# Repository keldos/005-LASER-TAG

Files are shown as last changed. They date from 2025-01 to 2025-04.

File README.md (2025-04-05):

# Wireless Comms, OLED Screen, and Ultra Beam Game for Laser Tag

## Description

This hack for the [Crunchlabs Hack Pack Box 5 - Laser Tag](https://www.crunchlabs.com/products/laser) adds an OLED screen that displays information for custom game modes, plus wireless communication between blasters using the nRF24L01+. The wireless comms enable new game mechanics such as an EMP blast and hit confirmation.

<p float="left">
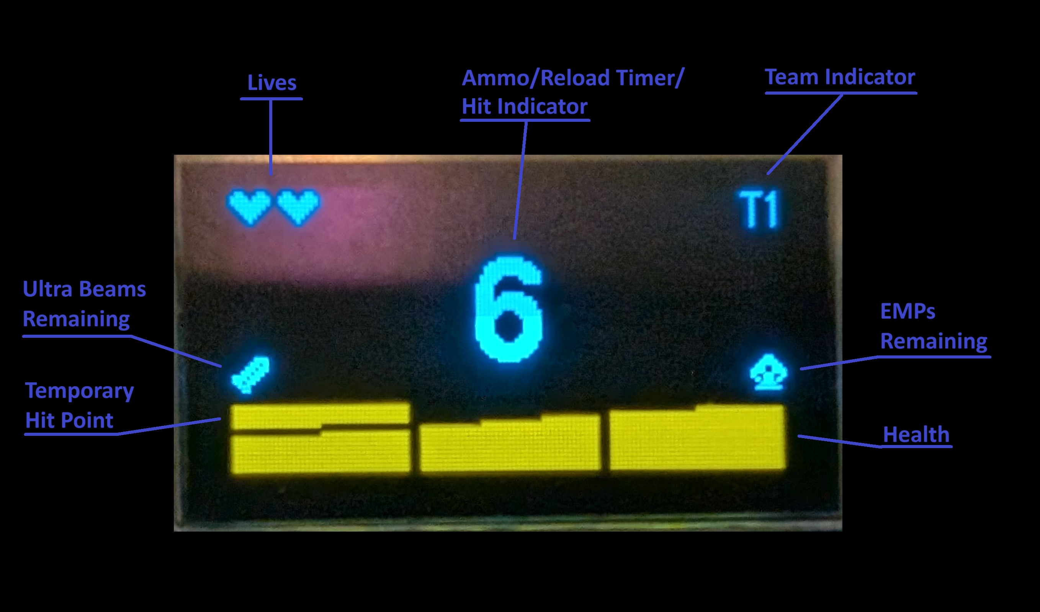
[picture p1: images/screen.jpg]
Screen with labels
  
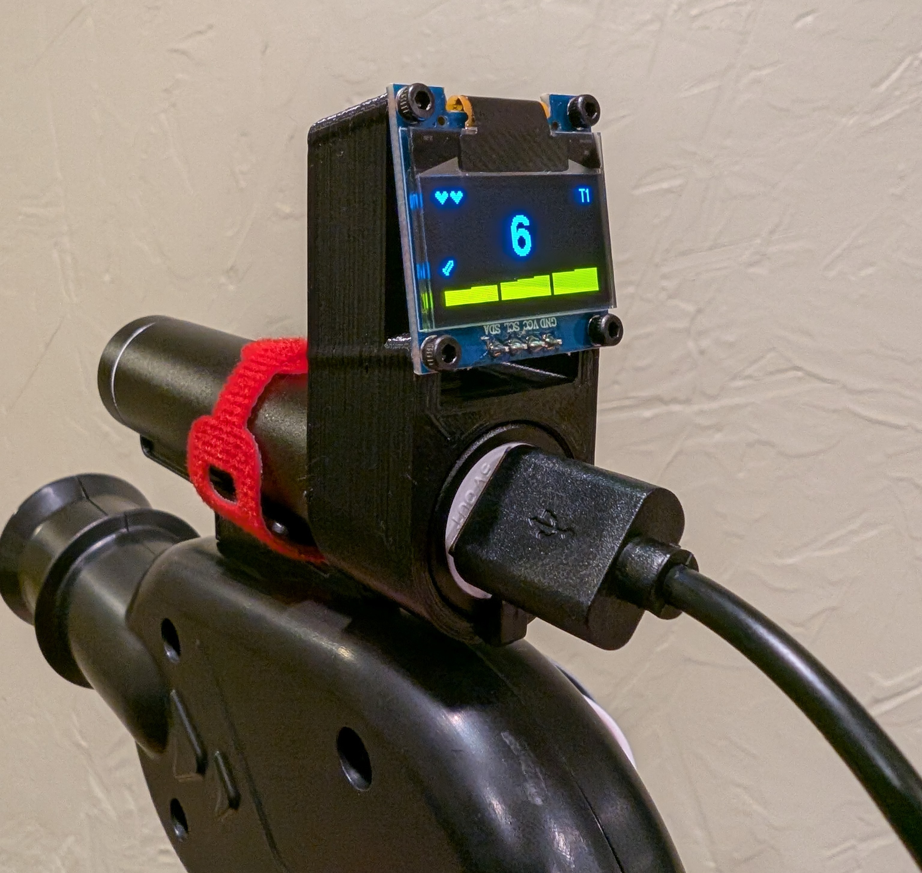
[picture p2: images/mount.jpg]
Screen mounted on battery
  
</p>

## Game Mechanics

* **Lives** - Each player starts with **2 lives**
* **Game Over** - Players reduced to 0 lives are out of the game with a **Game Over** screen
* **3 Health per life** – The goggles dim by 1/3 per health lost
* **6 Max Ammo** – Reload 1 ammo per second while holding the reload button
* **Ultra Beam:**
  * Charge the **Ultra Beam** by holding reload for 5 seconds when your ammo is maxed out
  * Fire a devastating shot that reduces your target's health to 0, but at a cost:
    * Lose 1 health
    * Consume all your ammo
    * Only 1 Ultra Beam per game
  * Make it count!
* **Team Selection** - When the game starts, you must select a team
  * Press reload to change teams
  * Hold the trigger for 2 seconds to start the game for everyone
  * Player icons are displayed indicating the number of players on each team
* **Successful Hit Indicator** - If a shot hits an enemy, the hit indicator will briefly display on your screen
  * The indicator changes slightly when your hit is a regular shot, Ultra Beam, or an elimination
* **Victory Screen** - If all opposing teams are eliminated, a victory screen will display
* **EMP Blast:**
  * An **EMP blast** is awarded when you are hit by an opponent's **Ultra Beam**
  * Hold the reload button and the trigger for 1 second to detonate an EMP blast
    * Grants you and nearby teammates with 1 temporary hitpoint for 20 seconds
      * The temporary hitpoint also protects you from Ultra Beam overload damage
    * Disables nearby enemies for 4 seconds
      * Disabled enemies can still be hit!
  * Coordinate for a devastating counter attack!

## OLED Screen Features

Displays critical game info, including:
* Ammo count
* Team number
* Lives
* Which team hit you
* Whether you were hit by an **Ultra Beam**

## Hardware

* [Crunchlabs Hack Pack Box 5 - Laser Tag](https://www.crunchlabs.com/products/laser)
* 2 [0.96 Inch OLED I2C Display Module](https://amzn.com/dp/B09C5K91H7)
* 2 [nRF24L01+ 2.4GHz Wireless RF Transceivers](https://amzn.com/dp/B07GZ17ZWS)
* 2 [Push Buttons](https://amzn.com/dp/B07ZV3PB26) for reload - Something with more of a click would be better
* 2 [3v Mini Vibration Motors](https://amzn.com/dp/B0B4SK8M1C)
* [Dupont Wires](https://amzn.com/dp/B07GD2BWPY)
* A 3D printer or access to one to print the screen mount (alternatively, the screen can be held on by strapping the wires down with the velcro battery strap)
* A Hot glue gun - The vibration motor adhesive did not hold
* A soldering iron
* 8 M2 screws - 4mm or longer
* Needle nose pliers - to remove plastic to make room for the nRF24L01+

## Wiring

### OLED:
* SDA -> A4
* SCL -> A5
* VCC -> 5v Rail
* GND -> GND Rail

### nRF24L01+:
* VCC -> 3v3 (NOT 5v!)
* GND -> GND Rail
* CE -> D2
* CSN -> D4
* MOSI -> D11
* MISO -> D12
* SCK -> D13

### Reload Button:
* Positive Terminal -> A0
* Negative Terminal -> GND Rail

### Vibration Motor:
* Positive Wire -> A2
* Negative Wire -> GND Rail

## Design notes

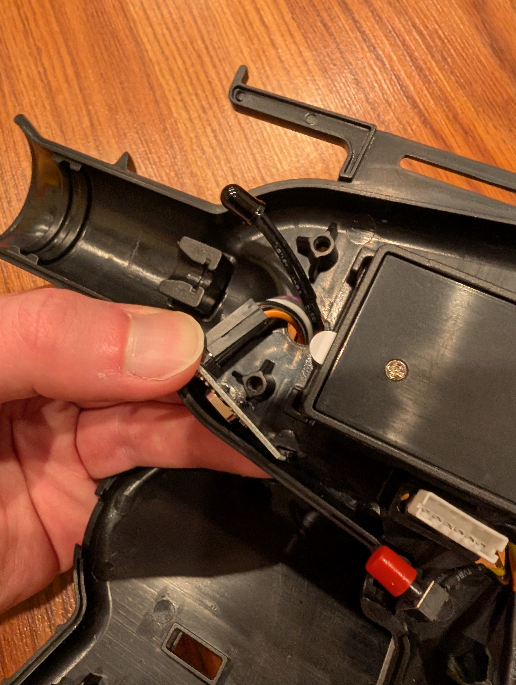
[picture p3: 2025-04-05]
images/rf-module.jpg

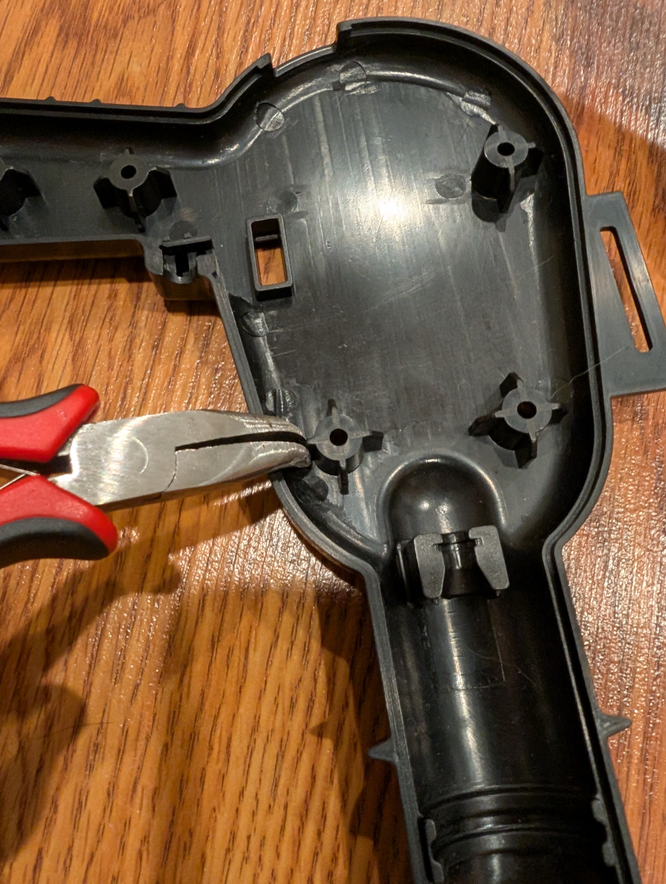
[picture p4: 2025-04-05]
images/remove-plastic.jpg

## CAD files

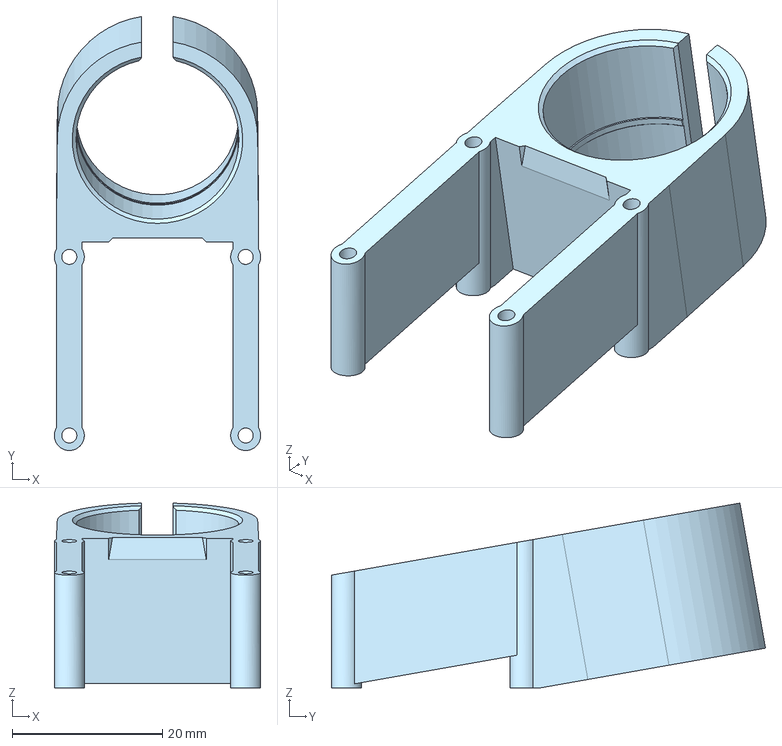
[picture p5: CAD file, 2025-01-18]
models/screen-mount.step
27.5 x 57.8 x 24.6 mm

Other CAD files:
models/screen-mount.3mf
models/screen-mount.stl

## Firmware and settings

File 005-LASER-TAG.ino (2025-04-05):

/*
  ************************************************************************************
  * MIT License
  *
  * Copyright (c) 2023 Crunchlabs LLC (Laser Tag Code)

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
  ************************************************************************************
*/

// >>>>>>>>>>>>>>>>>>>>>>>>>>>> PIN DEFINITIONS <<<<<<<<<<<<<<<<<<<<<<<<<<<<
#define IR_SEND_PIN         3
#define IR_RECEIVE_PIN      5
#define _IR_TIMING_TEST_PIN 7

#define SERVO_PIN       9

#define RELOAD_PIN      14 // A0 pin
#define BUZZER_PIN      16 // A2 pin
#define TRIGGER_PIN     17 // A3 pin

#define COMMS_CE        2
#define COMMS_CSN       4

// >>>>>>>>>>>>>>>>>>>>>>>>>>>>>>> LIBRARIES <<<<<<<<<<<<<<<<<<<<<<<<<<<<<<<
#define DECODE_NEC              // defines RIR Protocol (Apple and Onkyo)

#include <IRremote.hpp>
#include <Arduino.h>
#include <Servo.h>
#include <U8g2lib.h>

#include <SPI.h>
#include <nRF24L01.h>
#include <RF24.h>

RF24 radio(COMMS_CE, COMMS_CSN); // CE, CSN
const byte address[6] = "00001";

enum class PacketType {
  Undefined,
  IAm,
  IAmError,
  StartGame,
  EMP,
  ImHit,
  ImEliminated,
};

struct DataPacket {
  unsigned int uniqueID = 0;
  PacketType type = PacketType::Undefined;
  uint8_t playerId = 255;
};

#define MAX_TEAM_PLAYERS    8 // Must be even!
#define ID_OFFSET           MAX_TEAM_PLAYERS
#define ID_RANGE            MAX_TEAM_PLAYERS * 2
unsigned long lastHeartbeat = 0;
unsigned int randomDelay = 1245;

char errorMsg[50];
bool displayError = false;

Servo myservo;
U8G2_SSD1306_128X64_NONAME_1_HW_I2C u8g2(U8G2_R2, U8X8_PIN_NONE);

uint8_t numHalfWidth[10] = {9,7,9,9,8,9,9,9,9,9};

// >>>>>>>>>>>>>>>>>>>>>>>>>>> GAME PARAMETERS <<<<<<<<<<<<<<<<<<<<<<<<<<<<<
#define DEBOUNCE_DELAY 20

#define SERVO_INITIAL_POS 150     // how agressively to undarken goggles
#define SERVO_READY_POS 120       // reduce aggresiveness near end of action
#define SERVO_STOP 90             // Stop the servo
#define SERVO_HIT_POS 50          // Darken all the way
#define SERVO_TIME_TO_33 400      // ms needed to darken by 1/3
#define SERVO_TIME_TO_66 800      // ms needed to darken by 2/3
#define SERVO_TIME_TO_100 1200    // ms needed to darken all the way

#define TRIGGER_COOLDOWN 500      // milliseconds
#define HIT_TIMEOUT 8000          // milliseconds
#define START_GAME_HOLD 2000      // milliseconds
#define EMP_HOLD 1000             // milliseconds
#define START_GAME_COUNTDOWN 4000 // milliseconds
#define DISABLED_TIMEOUT 4000     // milliseconds
#define SHIELD_TIMER 20000        // milliseconds
#define RELOAD_TIME_EACH 1000     // milliseconds
#define CHARGE_ULTRA_BEAM 5000    // milliseconds
#define HIT_INDICATOR 2000        // milliseconds

const uint8_t maxAmmo = 6;
const uint8_t maxEMP = 1;
const bool deathTakesAmmo = true;
uint8_t playerId = 255;
uint8_t playerIdx = 255;
unsigned int uniqueID;
bool eliminated = false;
uint8_t eliminatedMe = 0;

uint8_t lastTriggerVal = 1;                 // trigger debounce variable
unsigned long lastTDebounceTime = 0;        // trigger button debounce time
uint8_t triggerState;                       // trigger debounce result
bool buttonWasReleased = true;              // release check, no "full auto"
unsigned long previousTriggerMillis = 0;    // cooldown timestamp between shots
unsigned long hitIndicatorTime = 0;         // hit indicator timeout

uint8_t lastReloadVal = 1;                  // reload button, debounce
unsigned long lastRDebounceTime = 0;        // reload button debounce time
uint8_t reloadState;                        // reload button debounce result
unsigned long buzzerTime = 0;               // when the buzzer should stop

unsigned long reloadTimer = -CHARGE_ULTRA_BEAM - 1000; // time to add shots to ammo bar

enum class GamePhase {
  PressStart,
  TeamSelect,
  GameCountdown,
  GameInProgress,
  GameOver,
};

enum class HitIndicator {
  None,
  Hit,
  UltraBeamHit,
  Elimination,
};

struct GameData {
  uint8_t ammo = maxAmmo;
  uint8_t emp = 0;
  uint8_t team = 3;
  uint8_t health = 3;
  uint8_t lives = 2;
  uint8_t hitTeam = 0;
  uint8_t hitUltraBeam = 0;
  uint8_t ultraBeamRemaining = 1;
  uint8_t team1PlayerCount = 0;
  uint8_t team2PlayerCount = 0;
  uint8_t team3PlayerCount = 0;
  bool shielded = false;
  bool disabled = false;
  bool isReloading = false;
  bool ultraBeamCharged = false;
  bool victory = false;
  HitIndicator hitIndicator = HitIndicator::None;
  GamePhase phase = GamePhase::PressStart;
};

GameData currentGD;

// These values should not change while still drawing screen
GameData drawGD;

struct PlayerData {
  unsigned int uniqueID = 0;
  unsigned int lastHeartbeat = 0;
  bool eliminated = false;
};

// Keep track of player stats
PlayerData registeredPlayers[3][MAX_TEAM_PLAYERS];

// Initialize game timeout variable
unsigned long timeoutStartTime = -HIT_TIMEOUT - 1000;
bool hitTimeout = false;
unsigned long gameInitiatedTime = 0;
unsigned long shieldStartTime = 0;
unsigned long disabledStartTime = 0;

// >>>>>>>>>>>>>>>>>>>>>>>>>>>> DISPLAY VARIABLES <<<<<<<<<<<<<<<<<<<<<<<<<<
bool pageDone = false;
float countdownBox = 0;
bool chargingUltraBeam = false;
bool chargingEMP = false;
uint8_t reloadArc = 0;
float empRadius = 0;
uint8_t gameStartCountdown = 3;

static const unsigned char heart_bitmap[] U8X8_PROGMEM = {
  0x00, 0x00,  // 00000000 00000000
  0xC6, 0x00,  // 11000110 00000000
  0xEF, 0x01,  // 11101111 00000001
  0xFF, 0x01,  // 11111111 00000001
  0xFE, 0x00,  // 11111110 00000000
  0x7C, 0x00,  // 01111100 00000000
  0x38, 0x00,  // 00111000 00000000
  0x10, 0x00   // 00010000 00000000
};

static const unsigned char ub_bitmap[] U8X8_PROGMEM = {
  0xE0,        // 11100000
  0xB0,        // 10110000
  0xD8,        // 11011000
  0x6C,        // 01101100
  0x37,        // 00110111
  0x1B,        // 00011011
  0x0E,        // 00001110
  0x0C         // 00001100
};

static const unsigned char remote_player_bitmap[] U8X8_PROGMEM = {
  0x00,        // 00000000
  0x0C,        // 00001100
  0x12,        // 00010010
  0x12,        // 00010010
  0x0C,        // 00001100
  0x12,        // 00010010
  0x21,        // 00100001
  0x3F,        // 00111111
};

static const unsigned char player_bitmap[] U8X8_PROGMEM = {
  0x00,        // 00000000
  0x0C,        // 00001100
  0x1E,        // 00011110
  0x1E,        // 00011110
  0x0C,        // 00001100
  0x1E,        // 00011110
  0x3F,        // 00111111
  0x3F,        // 00111111
};

static const unsigned char emp_bitmap[] U8X8_PROGMEM = {
  0x18,        // 00011000
  0x3C,        // 00111100
  0x66,        // 01100110
  0xE7,        // 11100111
  0x99,        // 10011001
  0x5A,        // 01011010
  0x3C,        // 00111100
  0x7E         // 01111110
};

// >>>>>>>>>>>>>>>>>>>>>>>>>>>>>>>> SETUP <<<<<<<<<<<<<<<<<<<<<<<<<<<<<<<<<<
void setup() {
  // Serial.begin(9600);

  u8g2.begin();

  // Move Goggles to start config
  myservo.attach(SERVO_PIN);
  myservo.write(SERVO_INITIAL_POS);
  delay(500);
  myservo.write(SERVO_READY_POS);
  delay(500);
  myservo.detach();

  pinMode(TRIGGER_PIN, INPUT_PULLUP);
  pinMode(RELOAD_PIN, INPUT_PULLUP);
  pinMode(BUZZER_PIN, OUTPUT);

  IrReceiver.begin(IR_RECEIVE_PIN, DISABLE_LED_FEEDBACK);

  // Set up RF module
  radio.begin();
  radio.setChannel(76);
  radio.openWritingPipe(address);
  radio.openReadingPipe(1, address); // Add reading pipe
  radio.setPALevel(RF24_PA_MIN);
  radio.setAutoAck(true);
  radio.startListening();

  // Set draw settings
  u8g2.setBitmapMode(1);
  u8g2.setDrawColor(2);
  u8g2.setFontMode(1);

  unsigned long seed = millis();

  // Gather entropy for a (hopefully) unique ID
  seed = (seed << 8) | analogRead(A1);
  seed = (seed << 8) | analogRead(A6);
  seed = (seed << 8) | analogRead(A7);

  randomSeed(seed);

  uniqueID = random(65535);
}

// >>>>>>>>>>>>>>>>>>>>>>>>>>>>>>>>>> LOOP <<<<<<<<<<<<<<<<<<<<<<<<<<<<<<<<<
void loop() {
  unsigned long currentMillis = millis();
  checkGameState(currentMillis);

  if (!currentGD.disabled) {
    ReadReloadButton(currentMillis);
    handleTrigger(currentMillis);
  }

  if (currentGD.phase == GamePhase::GameInProgress) {
    handleIRReception();

    if (currentGD.isReloading
        && (currentGD.ammo < maxAmmo
          || (currentGD.ultraBeamRemaining > 0
            && !currentGD.ultraBeamCharged))) {
      UpdateAmmo(true, currentMillis);
    }
  }

  recieveData();
  if (currentGD.phase != GamePhase::PressStart) {
    heartBeat(currentMillis);
  }

  updateDisplay(currentMillis);
}

// >>>>>>>>>>>>>>>>>>>>>>>>>>>> UI FUNCTIONS <<<<<<<<<<<<<<<<<<<<<<<<<<<<<
// Draw screen only as needed to minimize processing time
void updateDisplay(unsigned long currentMillis) {
  if (pageDone) {
    // If page is done drawing, check to see if it needs updating
    if (!gameDataEquals(drawGD, currentGD)
        || currentMillis - timeoutStartTime < HIT_TIMEOUT
        || currentGD.isReloading
        || (currentGD.emp > 0 && !buttonWasReleased && currentGD.isReloading && currentMillis - previousTriggerMillis <= EMP_HOLD)
        || currentGD.phase == GamePhase::GameCountdown
        || currentGD.phase == GamePhase::TeamSelect) {

      chargingUltraBeam = false;

      if (currentGD.ammo < maxAmmo && currentGD.isReloading) {
        reloadArc = max(255 - (currentMillis - reloadTimer) * 255 / RELOAD_TIME_EACH, 0);
      } else if (currentGD.ammo == maxAmmo && currentGD.isReloading && currentGD.ultraBeamRemaining > 0) {
        reloadArc = max(255 - (currentMillis - reloadTimer) * 255 / CHARGE_ULTRA_BEAM, 0);
        chargingUltraBeam = true;
      }

      countdownBox = 0;
      if (hitTimeout) {
        countdownBox = min((float)(currentMillis - timeoutStartTime) / HIT_TIMEOUT, 1.0);
      } else if (currentGD.phase == GamePhase::TeamSelect && !buttonWasReleased) {
        countdownBox = min((float)(currentMillis - previousTriggerMillis) / START_GAME_HOLD, 1.0);
      }

      drawGD = currentGD;

      chargingEMP = false;
      if (currentGD.emp > 0 && currentGD.isReloading && !buttonWasReleased && currentMillis - previousTriggerMillis <= EMP_HOLD) {
        chargingEMP = true;
        drawGD.emp = currentGD.emp - 1;
        empRadius = min((float)(currentMillis - previousTriggerMillis) / EMP_HOLD, 1.0);
      }

      if (currentGD.phase == GamePhase::GameCountdown) {
        gameStartCountdown = 3 - (currentMillis - gameInitiatedTime) / 1000;
      }

      pageDone = false;
    }
    if (!pageDone) {
      u8g2.firstPage();
    }
  }
  if (!pageDone) {

    if (drawGD.phase != GamePhase::PressStart) {
      drawStatus();
    }

    if(currentGD.phase == GamePhase::TeamSelect) {
      drawButtonHoldBox();
    }

    u8g2.setFont(u8g2_font_helvB14_tr);
    u8g2.setFontPosTop();

    if (drawGD.phase == GamePhase::PressStart) {
      drawPressStart();
    } else if (drawGD.phase == GamePhase::GameCountdown) {
      drawGameStartCountdown();
    } else if (drawGD.phase == GamePhase::TeamSelect) {
      drawTeamSelect();
    } else if (drawGD.phase == GamePhase::GameOver) {
      drawGameOver();
    } else if (drawGD.hitTeam > 0 || drawGD.hitUltraBeam > 0) {
      drawHitNotification();
    } else if (drawGD.ultraBeamCharged) {
      drawUltraBeamCharged();
    } else {
      drawAmmo();
      drawHitIndicator();
    }

    if (drawGD.phase != GamePhase::PressStart && !displayError) {
      drawHealth();
    } else if (displayError) {
      u8g2.setCursor(0, 48);
      u8g2.setFont(u8g2_font_helvR08_tr);
      u8g2.print("E: ");
      u8g2.print(errorMsg);
    }

    if (!u8g2.nextPage()) {
      pageDone = true;
    }
  }
}

bool gameDataEquals(const GameData& s1, const GameData& s2) {
  return s1.ammo == s2.ammo
      && s1.emp == s2.emp
      && s1.health == s2.health
      && s1.lives == s2.lives
      && s1.hitTeam == s2.hitTeam
      && s1.hitUltraBeam == s2.hitUltraBeam
      && s1.ultraBeamRemaining == s2.ultraBeamRemaining
      && s1.team1PlayerCount == s2.team1PlayerCount
      && s1.team2PlayerCount == s2.team2PlayerCount
      && s1.team3PlayerCount == s2.team3PlayerCount
      && s1.shielded == s2.shielded
      && s1.disabled == s2.disabled
      && s1.isReloading == s2.isReloading
      && s1.ultraBeamCharged == s2.ultraBeamCharged
      && s1.hitIndicator == s2.hitIndicator
      && s1.phase == s2.phase;
}

void drawStatus() {
  u8g2.setCursor(118, 0);
  u8g2.setFont(u8g2_font_helvR08_tr);
  u8g2.setFontPosTop();
  u8g2.print("T");
  u8g2.print(drawGD.team);

  for (uint8_t x = 0; x < drawGD.lives; x++) {
    u8g2.drawXBMP(0 + x * 11, 0, 16, 8, heart_bitmap);
  }
}

void drawButtonHoldBox() {
  u8g2.drawBox(0, 0, 128 * countdownBox, 48);
}

void drawPressStart() {
  u8g2.setCursor(32, 9);
  u8g2.print("PRESS");
  u8g2.setCursor(32, 27);
  u8g2.print("START");
}

void drawTeamSelect() {
  u8g2.setFont(u8g2_font_helvR08_tr);
  u8g2.setCursor(10, 9);
  u8g2.print("Select Team");

  const uint8_t offset = 10;
  for (uint8_t i = 1; i <= 3; i++) {
    u8g2.setCursor(10, 9 + i * offset);
    u8g2.print("T");
    u8g2.print(i);

    uint8_t teamCount = getTeamCount(drawGD, i-1);
    teamCount -= drawGD.team == i ? 1 : 0;
    if (teamCount >= MAX_TEAM_PLAYERS) {
      u8g2.setCursor(30, 9 + i * offset);
      u8g2.print("FULL");
    } else {
      for (uint8_t j = 0; j < teamCount; j++) {
        u8g2.drawXBMP(23 + j * 8, 10 + i * offset, 8, 8, remote_player_bitmap);
      }
    }
  }

  u8g2.drawXBMP(3, 10 + drawGD.team * offset, 8, 8, player_bitmap);
}

void drawHitNotification() {
  // Cooldown bar
  u8g2.drawBox(0, 0, 128 * (1.0 - countdownBox), 47);

  if (drawGD.hitTeam == drawGD.team) {
    u8g2.setCursor(10, 9);
    u8g2.print("OVERLOAD");
    u8g2.setCursor(20, 27);
    u8g2.print("DAMAGE");
  } else if (drawGD.hitUltraBeam > 0) {
    u8g2.setCursor(0, 9);
    u8g2.print("ULTRA BEAM");
    u8g2.setCursor(0, 27);
    u8g2.print("FROM TEAM ");
    u8g2.print(drawGD.hitUltraBeam);
  } else if (drawGD.disabled) {
    u8g2.setCursor(10, 9);
    u8g2.print("EMP BLAST");
    u8g2.setCursor(0, 27);
    u8g2.print("FROM TEAM ");
    u8g2.print(drawGD.hitTeam);
  } else {
    u8g2.setCursor(20, 9);
    u8g2.print("HIT FROM");
    u8g2.setCursor(20, 27);
    u8g2.print("TEAM ");
    u8g2.print(drawGD.hitTeam);
  }
}

void drawUltraBeamCharged() {
  u8g2.setCursor(1, 9);
  u8g2.print("ULTRA BEAM");
  u8g2.setCursor(17, 27);
  u8g2.print("CHARGED");
}

void drawGameStartCountdown() {
  if(gameStartCountdown == 0) {
    u8g2.setCursor(27, 22);
    u8g2.print("START!");
  } else {
    u8g2.setFont(u8g2_font_helvB24_tn);
    u8g2.setFontPosCenter();
    u8g2.setCursor(64 - numHalfWidth[gameStartCountdown], 31);
    u8g2.print(gameStartCountdown);
  }
}

void drawAmmo() {
  u8g2.setFontPosCenter();
  u8g2.setCursor(64 - numHalfWidth[drawGD.ammo], 31);
  u8g2.setFont(u8g2_font_helvB24_tn);
  u8g2.print(drawGD.ammo);


  // EMP Radius
  if (chargingEMP) {
    u8g2.drawCircle(96, 27, 17);
    u8g2.drawDisc(96, 27, 3 + empRadius * 15);
    u8g2.drawXBMP(92, 23, 8, 8, emp_bitmap);
  } else {
    // Reload Arc
    if (drawGD.isReloading && drawGD.ammo < maxAmmo || chargingUltraBeam) {
      u8g2.drawArc(64, 27, 20, reloadArc, 0);
      if (chargingUltraBeam) {
        u8g2.drawArc(64, 27, 18, reloadArc, 0);
        u8g2.drawArc(64, 27, 16, reloadArc, 0);
      }
    }
  }

  for (uint8_t x = 0; x < drawGD.ultraBeamRemaining; x++) {
    u8g2.drawXBMP(x * 11, 39, 8, 8, ub_bitmap);
  }

  for (uint8_t x = 0; x < drawGD.emp; x++) {
    u8g2.drawXBMP(120 - x * 11, 39, 8, 8, emp_bitmap);
  }
}

void drawHitIndicator() {
  if (drawGD.hitIndicator == HitIndicator::Hit) {
    u8g2.drawLine(64, 0, 64, 9);
    u8g2.drawLine(46, 27, 37, 27);
    u8g2.drawLine(82, 27, 91, 27);
  } else if (drawGD.hitIndicator == HitIndicator::UltraBeamHit) {
    u8g2.drawLine(63, 0, 63, 9);
    u8g2.drawLine(65, 0, 65, 9);
    u8g2.drawLine(46, 27, 37, 27);
    u8g2.drawLine(46, 29, 37, 29);
    u8g2.drawLine(82, 27, 91, 27);
    u8g2.drawLine(82, 29, 91, 29);
  } else if (drawGD.hitIndicator == HitIndicator::Elimination) {
    u8g2.drawLine(64, 0, 60, 10);
    u8g2.drawLine(64, 0, 68, 10);
    u8g2.drawLine(46, 27, 37, 27);
    u8g2.drawLine(46, 32, 37, 27);
    u8g2.drawLine(82, 27, 91, 27);
    u8g2.drawLine(82, 32, 91, 27);
  }
}

void drawHealth() {
  if (drawGD.shielded) {
    u8g2.drawTriangle(0,48, 40,48, 0,53);
    u8g2.drawTriangle(40,51, 40,48, 0,53);
  }
  if (drawGD.health > 0) {
    u8g2.drawTriangle(0,55, 40,53, 0,63);
    u8g2.drawTriangle(40,63, 40,53, 0,63);
  }
  if (drawGD.health > 1) {
    u8g2.drawTriangle(43,53, 84,50, 43,63);
    u8g2.drawTriangle(84,63, 84,50, 43,63);
  }
  if (drawGD.health > 2) {
    u8g2.drawTriangle(87,50, 127,48, 87,63);
    u8g2.drawTriangle(127,63, 127,48, 87,63);
  }
}

void drawGameOver() {
  if (currentGD.victory) {
    u8g2.setCursor(18, 22);
    u8g2.print("VICTORY!");
  } else {
    u8g2.setCursor(35, 9);
    u8g2.print("GAME");
    u8g2.setCursor(35, 27);
    u8g2.print("OVER");
  }
}

void broadcast(PacketType type, uint8_t sendPlayerId = 0) {
  DataPacket data;
  data.uniqueID = uniqueID;
  data.type = type;
  data.playerId = sendPlayerId;

  radio.stopListening();
  radio.write(&data, sizeof(data));
  radio.startListening();
}

// >>>>>>>>>>>>>>>>>>>>>>>>>>>> GAMEPLAY FUNCTIONS <<<<<<<<<<<<<<<<<<<<<<<<<<<<<
// Read Trigger ----------
void handleTrigger(unsigned long currentMillis) {
  bool triggerPressed = ReadTriggerButton();

  if (triggerPressed && buttonWasReleased && currentGD.ammo > 0 && currentMillis - previousTriggerMillis >= TRIGGER_COOLDOWN) {
    previousTriggerMillis = currentMillis;
    buttonWasReleased = false;

    if (currentGD.phase == GamePhase::GameInProgress && !currentGD.isReloading) {
      buzzFor(200);
      sendIR_Pulse();
      UpdateAmmo(false, currentMillis);
    } else if (currentGD.phase == GamePhase::PressStart) {
      if (changeTeam()) {
        currentGD.phase = GamePhase::TeamSelect;
      }
    }
  } else if (!triggerPressed) {
    buttonWasReleased = true;
  } else if (currentGD.phase == GamePhase::TeamSelect && !buttonWasReleased) {
    if (currentMillis - previousTriggerMillis >= START_GAME_HOLD) {
      broadcast(PacketType::StartGame);
      broadcast(PacketType::StartGame);
      initiateGame();
      releaseTriggerButton();
    }
  } else if (currentGD.emp > 0 && currentGD.isReloading && currentGD.phase == GamePhase::GameInProgress && !buttonWasReleased && !currentGD.ultraBeamCharged) {
    if (currentMillis - previousTriggerMillis >= EMP_HOLD) {
      broadcast(PacketType::EMP, playerId);
      buzzFor(200);
      currentGD.emp -= 1;
      applyFriendlyEMP();
      releaseTriggerButton();
      currentGD.isReloading = false;
      reloadTimer = currentMillis;
    }
  }
}

void releaseTriggerButton() {
  buttonWasReleased = true;
  previousTriggerMillis = millis();
}

void buzzFor(unsigned long time) {
  buzzerTime = millis() + time;
  digitalWrite(BUZZER_PIN, HIGH);
}

// Fire "Shot" ----------
void sendIR_Pulse() {
  Serial.flush();
  if (currentGD.ultraBeamCharged) {
    IrSender.sendNEC(0x00, playerId + 1, 5);
    markHit(currentGD.team); // Self hit
  } else {
    IrSender.sendNEC(0x00, playerId, 3);
  }
  delay(10);
}

// Read incoming message ----------
void handleIRReception() {
  if (IrReceiver.decode()) {
    checkPlayerHit();
    IrReceiver.resume(); // Ensure IR receiver is reset
  }
}

// Check if message is a "shot" from an enemy team ----------
void checkPlayerHit() {
  if (IrReceiver.decodedIRData.command == 0) {
    return;
  }
  uint8_t fromTeam = getTeamIndex(IrReceiver.decodedIRData.command) + 1;
  if (fromTeam != currentGD.team) {
    if (millis() - timeoutStartTime > HIT_TIMEOUT + 1000) {
      markHit(fromTeam);
    }
  }
}
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
